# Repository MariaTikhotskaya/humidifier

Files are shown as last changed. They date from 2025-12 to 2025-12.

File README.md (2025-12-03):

Увлажнитель — ядро нашего проекта. Для него мы купили пьезоэлемент — ультразвуковую мембрану, распыляющую воду. Для работы такой мембраны необходим ток с частотой ~108 кГц (к сожалению, поняли мы это далеко не сразу...) Сначала мы хотели самостоятельно собрать схему, которая способна его обеспечивать. Но оказалось, что для такой схемы необходимо очень тщательно подбирать компоненты и их параметры, поэтому мы решили, что выполнение этой работы — не рационально. Именно поэтому в проекте мы используем уже готовую плату, обеспечивающую необходимую частоту. Мы переделали подачу питания на неё, и теперь она питается от ESP32, а её включением/выключением мы можем управлять с помощью реле.

Изменение направления подачи тумана. Из разных вариантов реализации направленной подачи мы в итоге выбрали такой: туман выходит из изогнутой на 45 градусов трубы, которая поворачивается на нужный угол с помощью сервопривода и системы шестеренок. Для успешной инициализации используется оптический концевик, который позволяет определять нулевое положение. Напечатать шестерёнки с первого раза, конечно, не получилось, и у нас было очень много тестовых вариантов. Буквально в последний день мы заметили, что у шестерёнок, у которых должно было быть одинаковое количество зубьев, оно отличается на 1... Пришлось переделывать.

Корпус.
Мы долго решали, как и что должно быть расположено для успешной работы. Основную сложность составляло обеспечить правильное зацепление шестеренок по высоте. Первоначально шестерни моделировались вручную, и из-за этого их параметры не совпадали между собой, что мешало корректной сборке. Позже мы узнали о специальном инструменте в SolidWorks (ToolBox), который позволяет создавать шестерни с одинаковым модулем, что как раз и обеспечивает их правильное соединение друг с другом. Дополнительной задачей было точно «посадить» все шестерни на нужные валы и элементы конструкции, подогнав их под необходимые размеры. Также важно было подобрать правильную длину крышки устройства, чтобы все компоненты закрывались корректно и не мешали движению механизма.
Помимо этого, освоили программу CorelDRAW, в которой превращали модели в чертежи и дорабатывали их

Датчики. Мы взяли готовые датчики, работающие по протоколу Zigbee. Они сообщаются с программой Home Assistant, которая с помощью MQTT брокера взаимодействует с ESP32.

Что мы не успели. Мы предполагали, что поворотом трубы мы будем управлять, используя энкодер. Поэтому он даже есть у нас в схеме. В процессе работы мы поняли, что реализовать поворот будет легче с помощью delay сервопривода. Поэтому мы  задаём сервоприводу количество времени, нужное для поворота на заданный угол.

Академическая ценность. Перед началом курса мы совсем не понимали, что и как делать. У нас были только какие-то бызовые навыки типо пайки и каких-то элементарных штук в солиде(с минимумом опыта) и все. И честно, мы в шоке, от того, что из этого всего выросло))

Чему мы научились: 
• 3Д моделирование и фрезерная резка
• Программирование микроконтроллеров 
• Изготовление печатной платы
• Монтаж и пайка электронных компонентов 

Итоги. Мы конечно несколько не успели довести все до ума, и многое делали в последний момент. (И очень надеемся, что на сдаче все внезапно не сломается). Но основная и большая часть работа была успешно выполнена (урааа!).

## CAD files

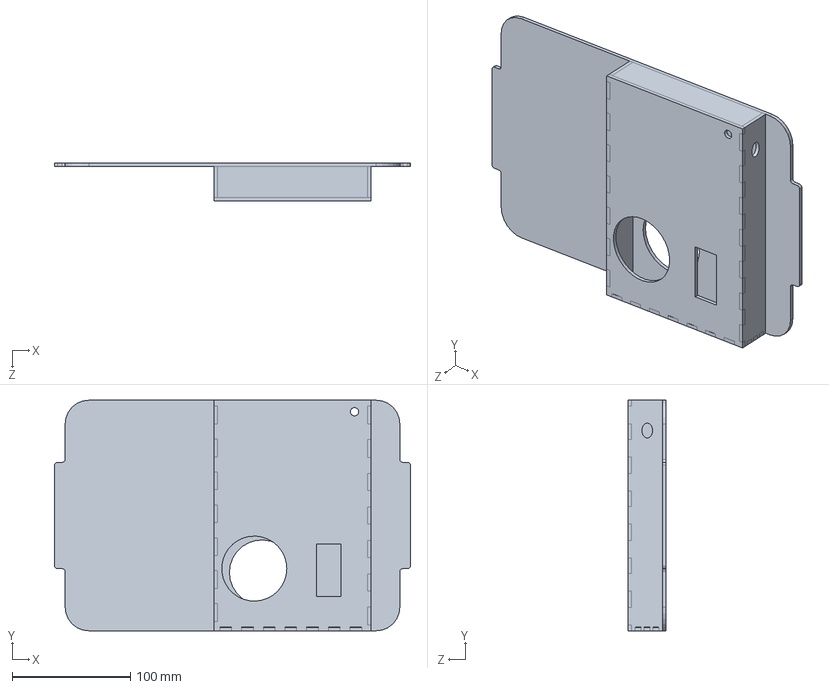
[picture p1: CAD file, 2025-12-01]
cap_korob.SLDPRT
301.0 x 195.0 x 31.9 mm

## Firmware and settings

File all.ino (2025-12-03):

#include <WiFi.h> //подключаем библиотеку для работы с WiFi
#include <PubSubClient.h> // подключаем библиотеку для работы с MQTT
#include <ESP32Servo.h>

//using namespace std;

// define
Servo servo1;
const int ButtonPin = 21;   // Кнопка 
const int servoPin = 2;     // Servo pin GPIO2
const int endPin = 15;// Оптический концевик GPIO15
const int rele = 22; // Реле
const int clk = 5; // энкодер
const int dt = 18; // энкодер 
const int sw = 19; // энкодер, кнопка


// датчики
float d1 = 25;
float d2 = 100;
float d3 = 27;
float d4 = 24;
int m0 = 0;
int m1 = 5;
// Переменные для управления состоянием
bool isRotating = false;
bool lastButtonState = HIGH;

// переменные для энкодера
int counter = 0;
int lastCLK = HIGH;
int lastSW = HIGH;

// Замените значения SSID/Password на те, что вы указали при настройке роутера
const char* ssid = "MTEST";
const char* password = "mtestpass";
const char* espHostname = "espNik32";

// Адрес MQTT брокера и логин/пароль:
const char* mqtt_server = "192.168.42.244";
const char* mqttUsr = "fab";
const char* mqttPass = "fabfabfab";

WiFiClient espClient; 
PubSubClient client(espClient);
long lastMsg = 0;
char msg[50];
int value = 0;
String inmsg = "";
int BUILTIN_LED = 19;

//String inmsg1 = "";

void setup_wifi() 
{
  delay(10);
  Serial.println();
  Serial.print("Connecting to ");
  Serial.println(ssid);

  WiFi.setHostname(espHostname);
  WiFi.begin(ssid, password);
  while (WiFi.status() != WL_CONNECTED) {
    delay(500);
    Serial.print(".");
  }

  Serial.println("");
  Serial.println("WiFi connected");
  Serial.println("IP address: ");
  Serial.println(WiFi.localIP());
}


void callback(char* topic, byte* payload, unsigned int length) {
  inmsg = "";
  // Serial.print("Message arrived [");
  Serial.print("] ");
  Serial.print(topic);
  
  Serial.print("сработал датчик0" + String(topic));
  //a = topic;
  for (int i = 0; i < length; i++) {
    inmsg += (char)payload[i];}
    //hd.push_back((char)payload[i]);
  if (String(topic) == "/humidifire/humiditysensor/01/"){
      d1 = inmsg.toFloat();
      }
    
  if (String(topic) == "/humidifire/humiditysensor/02/"){
      d2 = inmsg.toFloat();}
    
  if (String(topic) == "/humidifire/humiditysensor/03/"){
      d3 = inmsg.toFloat();}
    
  if (String(topic) == "/humidifire/humiditysensor/04/"){
      d4 = inmsg.toFloat();}
    
    // Serial.print((char)payload[i]);
  // Serial.println(inmsg);
  // Serial.println("from topic: " + inmsg);
  float  m = minimum(d1, d2, d3, d4);
  if (m == d4){
    m1 = 4;
    Serial.print("aaaaaaaaaa");}
  if (m == d1){
    m1 = 1;
    Serial.print("bbbbbbbbbbb");}
  if (m == d3){
    m1 = 3;
    Serial.print("cccccccccccc");}
  Serial.print(m1);
  Serial.print(m0);
  if (m0!=m1){
    init_without_button();
    rotate_servo(m);}

  if ((String)inmsg.c_str() == "off") {
    digitalWrite(BUILTIN_LED,  HIGH); // выключаем светодиод
    //Serial.println(String(inmsg.c_str()) + "dd");
    sendData("/miptfab/esp32led/ledState/", "OFF"); // отправляем состояние светодиода
  } else {//вот в этом месте приходят данные в порт если датчики тригерят
    digitalWrite(BUILTIN_LED, HIGH); // включаем светодиод
    delay(3000);
    digitalWrite(BUILTIN_LED, LOW);
    Serial.println(inmsg.c_str());
    sendData("/miptfab/esp32led/ledState/", "ON"); // отправляем состояние светодиода
  }
}

void reconnect() {
  while (!client.connected()) {
    Serial.print("Attempting MQTT connection...");
    String clientId = "esp32testClient-";
    clientId += String(random(0xffff), HEX);
    // пытаемся подключиться к брокеру MQTT
    if (client.connect(clientId.c_str(), mqttUsr, mqttPass)) {
      Serial.println("connected");
      // Как только подключились, сообщаем эту прекрасную весть...
      client.publish("/humidifire/state/", "connected");
      // ... ну и переподписываемся на нужный топик
      client.subscribe("/humidifire/humiditysensor/#");

    } else {
      Serial.print("failed, rc=");
      Serial.print(client.state());
      Serial.println(" try again in 5 seconds");
      // Ждём 5 секунд перед следующей попыткой подключиться к брокеру MQTT
      delay(5000);
    }
  }
}



bool sendData(String topic, String data) {
  // String msgj = paramOne;
  if (!client.connected()) {
    reconnect();
  } else {
    client.publish(topic.c_str(), data.c_str());
     Serial.println(topic + " " + data);
  }
  return true;
}

void init_without_button(){
  bool isRotating = false;
  int endValue = digitalRead(endPin);   
  if (!isRotating) {
      // Запускаем вращение
      
      isRotating = true;
      // Подключаем серво
      if (!servo1.attached()) {
          servo1.attach(servoPin);
      }
      // Запускаем вращение
      servo1.write(94);
         
  } /*else {
      // Останавливаем вращение при повторном нажатии
      isRotating = false;
      // Останавливаем серво
      servo1.write(93); // Стоп
      delay(1000);
      servo1.detach();
      delay(1000);
  }*/

  bool flag = true;
  // Если серво вращается, проверяем концевик
  while (flag == true) {
      // Проверяем оптический концевик
      if (digitalRead(endPin) == HIGH) {
          // Концевик сработал - останавливаем
          isRotating = false;
          servo1.write(93); // Стоп
          delay(1000);
          servo1.detach();
          delay(2000);
          flag = false;
          //lastButtonState = HIGH;
      } else {
          // Продолжаем вращение
          delay(50);
      }
  }
  
  delay(100);
}


float rotate_servo(float d){
  int endValue = digitalRead(endPin);
  if (!servo1.attached()) {
              servo1.attach(servoPin);
          }
  if (d == d4){
    m0 = 4;
    Serial.print("Четвертый");
    Serial.print(d4);
    servo1.write(94);
    delay(2250);
    servo1.write(93); // Стоп
    delay(1000);
    servo1.detach();
    delay(1000);
  }

  

  if (d == d3){
    m0 = 3;
    Serial.print("Третий");
    servo1.write(94);
    delay(1125);
    servo1.write(93); // Стоп
    delay(1000);
    servo1.detach();
    delay(1000);
  }

  if (d == d1){
    m0 = 1;
    Serial.print("Первый");
    servo1.write(94);
    delay(5500);
    servo1.write(93); // Стоп
    delay(1000);
    servo1.detach();
    delay(1000);
  }

  return 0;
}



/*void rotate_servo_4(){
  int endValue = digitalRead(endPin);
  if (!servo1.attached()) {
              servo1.attach(servoPin);
          }
  servo1.write(94);
  delay(2250);
  servo1.write(93); // Стоп
          delay(1000);
          servo1.detach();
          delay(1000);
  
  }

void rotate_servo_1(){
int endValue = digitalRead(endPin);
if (!servo1.attached()) {
            servo1.attach(servoPin);
        }
servo1.write(94);
delay(3375);
servo1.write(93); // Стоп
        delay(1000);
        servo1.detach();
        delay(1000);

}

void rotate_servo_3(){
  int endValue = digitalRead(endPin);
  if (!servo1.attached()) {
              servo1.attach(servoPin);
          }
  servo1.write(94);
  delay(1125);
  servo1.write(93); // Стоп
          delay(1000);
          servo1.detach();
          delay(1000);
  
  }
  */
void init(){
  int buttonState = digitalRead(ButtonPin);
  int endValue = digitalRead(endPin);
  //digitalWrite(rele, HIGH);
  // Если кнопка нажата 
  if (buttonState == LOW && lastButtonState == HIGH) {
      
      if (!isRotating) {
          // Запускаем вращение
          
          isRotating = true;
          // Подключаем серво
          if (!servo1.attached()) {
              servo1.attach(servoPin);
          }
          // Запускаем вращение
          servo1.write(94);
          
          
          
      } else {
          // Останавливаем вращение при повторном нажатии
          isRotating = false;
          // Останавливаем серво
          servo1.write(93); // Стоп
          delay(1000);
          servo1.detach();
          delay(1000);
      }
  }
  lastButtonState = buttonState;
  
  // Если серво вращается, проверяем концевик
  if (isRotating) {
      // Проверяем оптический концевик
      if (digitalRead(endPin) == HIGH) {
          // Концевик сработал - останавливаем
          isRotating = false;
          servo1.write(93); // Стоп
          delay(1000);
          servo1.detach();
          delay(2000);
          //lastButtonState = HIGH;
      } else {
          // Продолжаем вращение
          delay(50);
      }
  }
  
  delay(100);
}
float minimum(float d1,float d2,float d3,float d4){
  float m = 100;
  if (d1<m){m = d1;}
  if (d2<m){m = d2;}
  if (d3<m){m = d3;}
  if (d4<m){m = d4;}
  return m;
  }
void encoder(){
  // Чтение энкодера
  int currentCLK = digitalRead(clk);
  if (currentCLK != lastCLK && currentCLK == LOW) {
    if (digitalRead(dt) == HIGH) {
      counter++;
    } else {
      counter--;
    }
    Serial.print("Count: ");
    Serial.println(counter);
  }
  lastCLK = currentCLK;
  
  // Обработка кнопки
  int currentSW = digitalRead(sw);
  if (currentSW == LOW && lastSW == HIGH) {
    delay(50); // Защита от дребезга
    counter = 0;
    Serial.println("Reset to 0");
    delay(300);
  }
  lastSW = currentSW;
  
  delay(1);
}

void setup() {
  Serial.begin(115200);
  //wifi
  pinMode(BUILTIN_LED, OUTPUT);
  setup_wifi();
  client.setServer(mqtt_server, 1883);
  client.setCallback(callback);
  digitalWrite(BUILTIN_LED, HIGH);
  delay(2500);
  digitalWrite(BUILTIN_LED, LOW);

  // servo
  servo1.attach(servoPin);
  pinMode(endPin, INPUT_PULLUP);     // Концевик с подтяжкой
  pinMode(ButtonPin, INPUT_PULLUP);

  // rele
  pinMode(rele, OUTPUT);
  digitalWrite(rele, LOW); // Выключить реле при старте

  // encoder

  pinMode(clk, INPUT_PULLUP);
  pinMode(dt, INPUT_PULLUP);
  pinMode(sw, INPUT_PULLUP);

  pinMode(ButtonPin, INPUT_PULLUP);

  digitalWrite(rele, HIGH); // Подать питание
  delay(1000); 
  }

void loop() {
  // WIFI
  /*if (touchRead(4)<20){
    Serial.println(touchRead(4));
    sendData("/humidifire/goto/", (String)touchRead(4));
  }*/
  
  if (!client.connected()) {
    reconnect();
    //sendData("/humidifire/state/", "up");
  }
  client.loop();
  //client.publish("/humidifire/humiditysensor/01/", "355");
  //sendData("/humidifire/state/", "up");
  // INIT
  init();
//float  m = minimum(d1, d2, d3, d4);
  //rotate_servo(m);
  //delay(10000);
  //init_without_button();
  //delay(1000);
  
  
  // включение увлажнителя
  //digitalWrite(rele, HIGH); // Подать питание
  //delay(1000); 
  //digitalWrite(rele, LOW); // Подать питание
  //delay(5000);
  // энкодер
  //encoder();
  
  /*if (digitalRead(endPin) == HIGH) {
    rotate_servo_3();
    }*/

  
  
}
